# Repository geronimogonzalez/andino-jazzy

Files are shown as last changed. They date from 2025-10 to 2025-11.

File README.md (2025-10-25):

# ANDINO
[**BUILING BRANCH**]

Andino is a fully open-source diff drive robot designed for educational purposes and low-cost applications.
It is fully integrated with ROS 2 and it is a great base platform to improve skills over the robotics field.
With its open-source design, anyone can modify and customize the robot to suit their specific needs.

<p align="center">
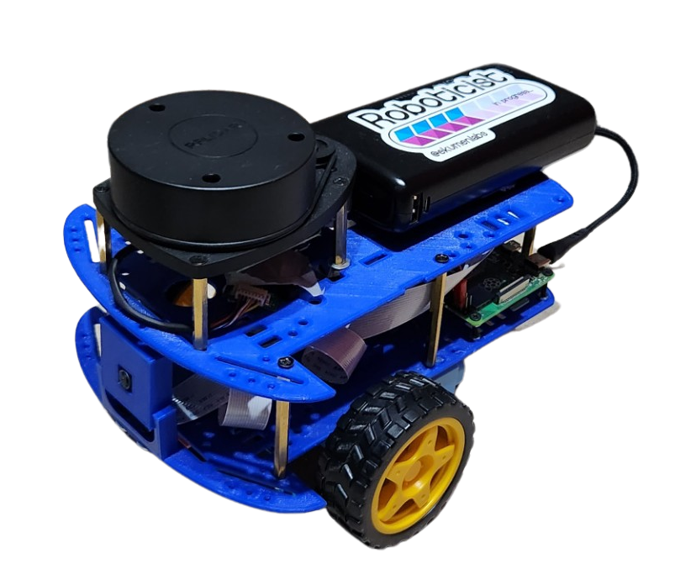
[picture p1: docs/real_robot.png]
  
</p>

_Note: For videos go to [Media](#selfie-media) section._

## :books: Package Summary

- :rocket: [`andino_bringup`](./andino_bringup): Contains mainly launch files in order to launch all related driver and nodes to be used in the real robot.
- :robot: [`andino_hardware`](./andino_hardware): Contains information about the Andino assembly and hardware parts.
- :ledger: [`andino_description`](./andino_description): Contains the URDF description of the robot.
- :hammer_and_pick: [`andino_firmware`](./andino_firmware): Contains the code be run in the microcontroller for interfacing low level hardware with the SBC.
- :gear: [`andino_base`](./andino_base): [ROS Control hardware interface](https://control.ros.org/master/doc/ros2_control/hardware_interface/doc/writing_new_hardware_interface.html) is implemented.
- :control_knobs: [`andino_control`](./andino_control/): It launches the [`controller_manager`](https://control.ros.org/humble/doc/ros2_control/controller_manager/doc/userdoc.html) along with the [ros2 controllers](https://control.ros.org/master/doc/ros2_controllers/doc/controllers_index.html): [diff_drive_controller](https://control.ros.org/master/doc/ros2_controllers/diff_drive_controller/doc/userdoc.html) and the [joint_state_broadcaster](https://control.ros.org/master/doc/ros2_controllers/joint_state_broadcaster/doc/userdoc.html).
- :world_map: [`andino_slam`](./andino_slam/): Provides support for SLAM with your `andino` robot.
- :compass: [`andino_navigation`](./andino_navigation/): Navigation stack based on `nav2`.

## :paperclips: Related projects

Other projects built upon Andino! :rocket:

- :computer: [`andino_gz`](https://github.com/Ekumen-OS/andino_gz): [Gazebo](https://gazebosim.org/home)(non-classic) simulation of the `andino` robot.
- :lady_beetle: [`andino_webots`](https://github.com/Ekumen-OS/andino_webots): [Webots](https://github.com/cyberbotics/webots) simulation of the Andino robot fully integrated with ROS 2.
- :joystick: [`andino_o3de`](https://github.com/Ekumen-OS/andino_o3de): [O3DE](https://o3de.org/) simulation of the Andino robot.
- :green_circle: [`andino_isaac`](https://github.com/Ekumen-OS/andino_isaac): [Isaac Sim](https://docs.omniverse.nvidia.com/isaacsim/latest/index.html) simulation of the Andino robot.
- :robot: [`andino_rmf`](https://github.com/Ekumen-OS/andino_rmf): [OpenRMF](https://www.open-rmf.org/) integration of Andino simulation.
- :test_tube: [`andino_integration_tests`](https://github.com/Ekumen-OS/andino_integration_tests): Extension to the Andino robot showing how to build integration tests.

## :busts_in_silhouette: Community

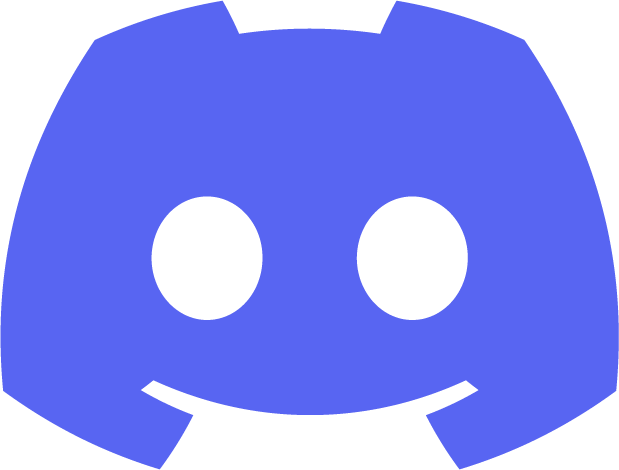
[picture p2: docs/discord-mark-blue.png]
[](https://discord.gg/tHhH32CTHu) Join our Discord and contribute to the community!

## :pick: Robot Assembly

Visit [`andino_hardware`](./andino_hardware/) for assembly instructions.

## :mechanical_arm: Installation

### Platforms

- ROS 2: Jazzy Jalisco
- OS:
  - Ubuntu 24.04 Noble Numbat
  - Ubuntu Server 24.04.1 (WIP) (On real robot (e.g: Raspberry Pi 4B))

### Build from Source

#### Dependencies

1. Install [ROS 2](https://docs.ros.org/en/jazzy/Installation/Ubuntu-Install-Debs.html)
2. Install [colcon](https://colcon.readthedocs.io/en/released/user/installation.html)

#### colcon workspace

Packages here provided are colcon packages. As such a colcon workspace is expected:

1. Create colcon workspace

```
mkdir -p ~/ws/src
```

2. Clone this repository in the `src` folder

```
cd ~/ws/src
```

```
git clone https://github.com/Ekumen-OS/andino.git
```

3. Install dependencies via `rosdep`

```
cd ~/ws
```

```
rosdep install --from-paths src --ignore-src -i -y
```

4. Build the packages

```
colcon build
```

5. Finally, source the built packages
   If using `bash`:

```
source install/setup.bash
```

`Note`: Whether your are installing the packages in your dev machine or in your robot the procedure is the same.

### Install the binaries

The packages have been also released via ROS package manager system for the 'humble' distro. You can check them [here](https://repo.ros2.org/status_page/ros_humble_default.html?q=andino).

These packages can be installed using `apt` (e.g: `sudo apt install ros-humble-andino-description`) or using `rosdep`.

## :rocket: Usage

### Robot bringup

`andino_bringup` contains launch files that concentrates the process that brings up the robot.

After installing and sourcing the andino's packages simply run.

```
ros2 launch andino_bringup andino_robot.launch.py
```

This launch files initializes the differential drive controller and brings ups the system to interface with ROS.
By default sensors like the camera and the lidar are initialized. This can be disabled via arguments and manage each initialization separately. See `ros2 launch andino_bringup andino_robot.launch.py -s ` for checking out the arguments.

- include_rplidar: `true` as default.
- include_camera: `true` as default.

After the robot is launched, use `ROS 2 CLI` for inspecting environment.
For example, by doing `ros2 topic list` the available topics can be displayed:

    /camera_info
    /cmd_vel
    /image_raw
    /odom
    /robot_description
    /scan
    /tf
    /tf_static

   _Note: Showing just some of them_

### Teleoperation

Launch files for using the keyboard or a joystick for teleoperating the robot are provided.

#### Keyboard

```
ros2 launch andino_bringup teleop_keyboard.launch.py
```
This is similarly to just executing `ros2 run teleop_twist_keyboard teleop_twist_keyboard`.

#### Joystick

Using a joystick for teleoperating is notably better.
You need the joystick configured as explained [here](andino_hardware/README.md#Using-joystick-for-teleoperation).
```
ros2 launch andino_bringup teleop_joystick.launch.py
```

### RViz

Use:

```
ros2 launch andino_bringup rviz.launch.py
```

For starting `rviz2` visualization with a provided configuration.

## :compass: Navigation

The [`andino_navigation`](./andino_navigation/README.md) package provides a navigation stack based on the great [Nav2](https://github.com/ros-planning/navigation2) package.

https://github.com/Ekumen-OS/andino/assets/53065142/29951e74-e604-4a6e-80fc-421c0c6d8fee

Follow the [`andino_navigation`'s README](./andino_navigation/README.md) instructions for bringing up the Navigation stack in the real robot or in the simulation.

## :selfie: Media

### RVIZ Visualization

https://github.com/Ekumen-OS/andino/assets/53065142/c9878894-1785-4b81-b1ce-80e07a27effd

### Slam

Using the robot for mapping.

https://github.com/Ekumen-OS/andino/assets/53065142/283f4afd-0f9a-4d37-b71f-c9d7b2f3e453

https://github.com/Ekumen-OS/andino/assets/53065142/d73f6053-b422-4334-8f62-029a38799e66

See [`andino_slam`](./andino_slam/) for more information.

## :robot: Share your Andino!

Have you built your `Andino` already? Please go to [`Show & Tell`](https://github.com/Ekumen-OS/andino/discussions/categories/show-and-tell) Discussion and share with us your own version of it.

## :star2: Inspirational sources

This section is dedicated to recognizing and expressing gratitude to the open-source repositories that have served as a source of inspiration for this project. We highly recommend exploring these repositories for further inspiration and learning.

 * [articubot_one](https://github.com/joshnewans/articubot_one)
 * [diffbot](https://github.com/ros-mobile-robots/diffbot)
 * [noah_hardware](https://github.com/GonzaCerv/noah-hardware)
 * [linorobot](https://github.com/linorobot/linorobot2)

## :raised_hands: Contributing

Issues or PRs are always welcome! Please refer to [CONTRIBUTING](CONTRIBUTING.md) doc.

## Code development

Note that a [`Docker`](./docker) folder is provided for easy setting up the workspace.

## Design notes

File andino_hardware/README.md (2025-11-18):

# andino_hardware

This package aims to provide the necessary information to the correct assembly of the robot.

## Bill of Materials

| Number | Module | Part | Links | Comments |
|:--:|:--:|:---:|:---:|:---:|
| 1 | SBC | Raspberry Pi 4 B (4 Gb) | [PiShop](https://www.pishop.us/product/raspberry-pi-4-model-b-2gb/), [TiendaTec](https://www.tiendatec.es/raspberry-pi/gama-raspberry-pi/1100-raspberry-pi-4-modelo-b-4gb-5056561800349.html) | If you want better performance you could buy the 8GB model |
| 2 | Chassis |  2 x Print 3d Chassis + Rubber Tyre Wheels | [Chassis](./printing_model/chassis/), [Wheels Sparkfun](https://www.sparkfun.com/products/13259) | - |
| 3 | Motors | 2 x Motor with Encoder | [Sparkfun](https://www.sparkfun.com/products/16413) | - |
| 4 | Microcontroller | Arduino Nano | [Amazon](https://www.amazon.es/RUIZHI-Interfaz-Controlador-Mejorada-Compatible/dp/B0CNGKG4MZ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) | You can also use an Arduino Uno, but mind size. It should include a microUSB - USB cable. If not, you will need to purchase it.  |
| 5 | Motor Driver | L298N Dual H Bridge | [Amazon](https://www.amazon.com/Bridge-Stepper-Driver-Module-Controller/dp/B09T6K9RFZ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) | - |
| 6 | Laser Scanner | RPLidar A1M8 | [RobotShop](https://www.robotshop.com/products/rplidar-a1m8-360-degree-laser-scanner-development-kit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), [Amazon](https://www.amazon.es/dp/B07VLFGT27?ref_=cm_sw_r_cso_wa_apan_dp_RJ3AZC2XCEVDK0X2DCGA&starsLeft=1&th=1) | If no microUSB-USB cable is included, you will need to purchase one |
| 7 | Camera | Raspi Camera Module V2, 8 MP | [Robotshop](https://www.robotshop.com/products/raspberry-pi-camera-module-v2), [Amazon](https://www.amazon.com/Raspberry-Pi-Camera-Module-Megapixel/dp/B01ER2SKFS?th=1), [Longer cable](https://www.amazon.es/AZDelivery-Repuesto-Raspberry-30cm-Flexkabel/dp/B01NAXKTDP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)  | A link for a longer cable (30 cm) is included, just in case the one included with the camera is too short. |
| 8 | Electrical Power Supply | Powerbank 5V | [Amazon](https://www.amazon.es/Heganus-Powerbank-10000mAh-port%C3%A1til-pr%C3%A1ctico/dp/B082PPPWXY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) | Any powerbank is suitable: Mind size / weight / output current(>=2A) |
| 9 | Power Step up | DC - DC boost converter | [Amazon Europe](https://www.amazon.es/Convertidor-convertidor-Controlador-almacenamiento-Transformadores/dp/B08D5XF571) | If motors support higher voltage than 5V a step-up(e.g: to 9V) can be added between powerbank (5V) and motor driver. Screw clockwise to reduce the output voltage. |
| 10 | Fixing & Mount | M3 bolts/fasteners - M3 Spacers - M2.5/2.0 bolts/fasteners for SBC | [Mercado Libre](https://articulo.mercadolibre.com.ar/MLA-823234605-kit-tornillos-electronica-500-unid-fresada-philips-m3-oferta-_JM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), [Amazon](https://www.amazon.com/Taiss-620PCS-Metric-Assortment-Washers/dp/B0CWXRG6VL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), [Spacers](https://www.amazon.es/YOKIVE-Separadores-Tornillos-Hexagonal-Consistente/dp/B0BWXL75R6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) | You will probably need to replace the default spacers for the LiDAR with M3 spacers |
| 11 | Other 3D printed parts | Camera Mount | [3D models](./printing_model/raspi_cam_mount/) | These parts are for fixing the Raspi Cam at the front of the robot |
| 12 | Caster wheel | Caster wheel | [Amazon](https://www.amazon.es/Unidades-Peque%C3%B1as-Dispositivo-Transferencia-Transporte/dp/B098XHYW7F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) | - |
| 13 | SD Card | 64 GB SD Card | [Apokin](https://www.apokin.es/tarjeta-microsd-philips-64gb-class10.html), [Amazon](https://www.amazon.es/Kingston-Tarjeta-SDCS2-64GB-Adaptador/dp/B07YGZQ4H8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) | The SD Card is used to host the OS for the Raspberry Pi |
| 14 | (Optional) Plastic seals | - | - | You will need at least 2 longer ones to fix the powerbank to the upper chassis, and the shorter ones for all the wires. If you don't want to use them, you can use other method to fix the powerbank and wires |

When you gather all the parts, you should have the following (NOTE: the printed encoder wheels are no longer necessary, since the motors are equipped with an embedded encoder):

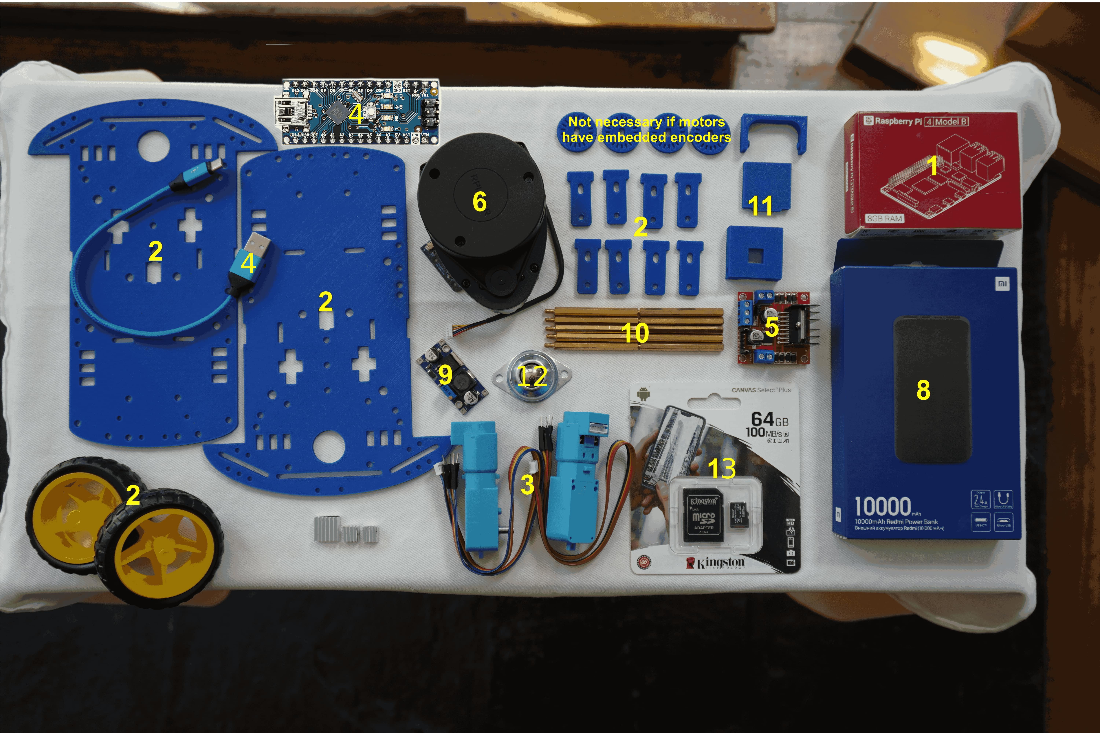
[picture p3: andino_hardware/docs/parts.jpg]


### Tooling

| Number | Tool | Links | Comments |
|:--:|:---:|:---:|:---:|
| 1 | Set of screwdrivers | [Amazon](https://www.amazon.es/Ainiv-Destornilladores-Precisi%C3%B3n-Destornillador-magnetizador/dp/B09CD1F44B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) | You need flat and star screwdrivers |
| 2 | Silicon Pistol | [Amazon](https://www.amazon.es/Tilswall-Pegamento-Manualidades-Bricolaje-Reparaciones/dp/B07TD1RD4R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) | This pistol should include 75 silicon bars so you won't need to purchase them separately |

## Assembly Process

  1. Screw the Motor Driver and the idler wheel to the lower chassis.

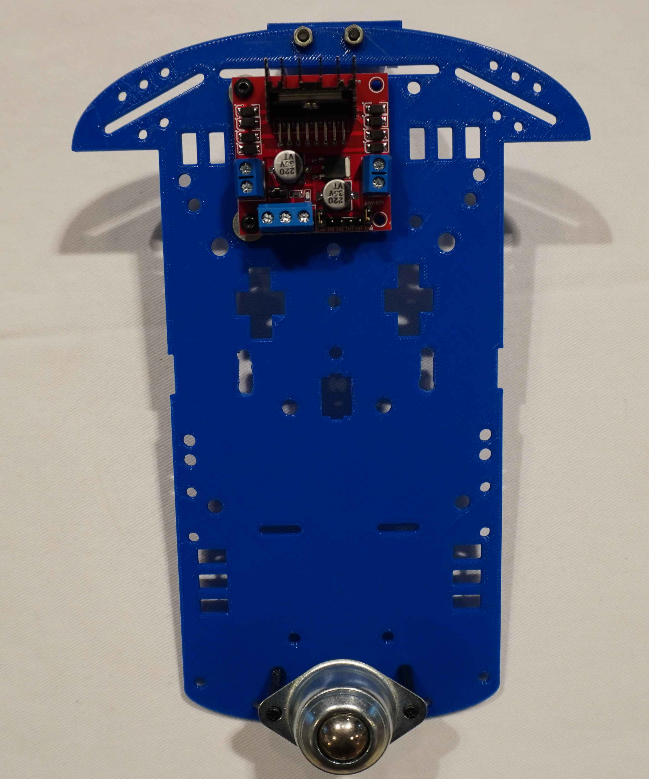
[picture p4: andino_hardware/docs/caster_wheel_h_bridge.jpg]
  

  Here you have a front image of how the caster wheel are mounted to the chassis:

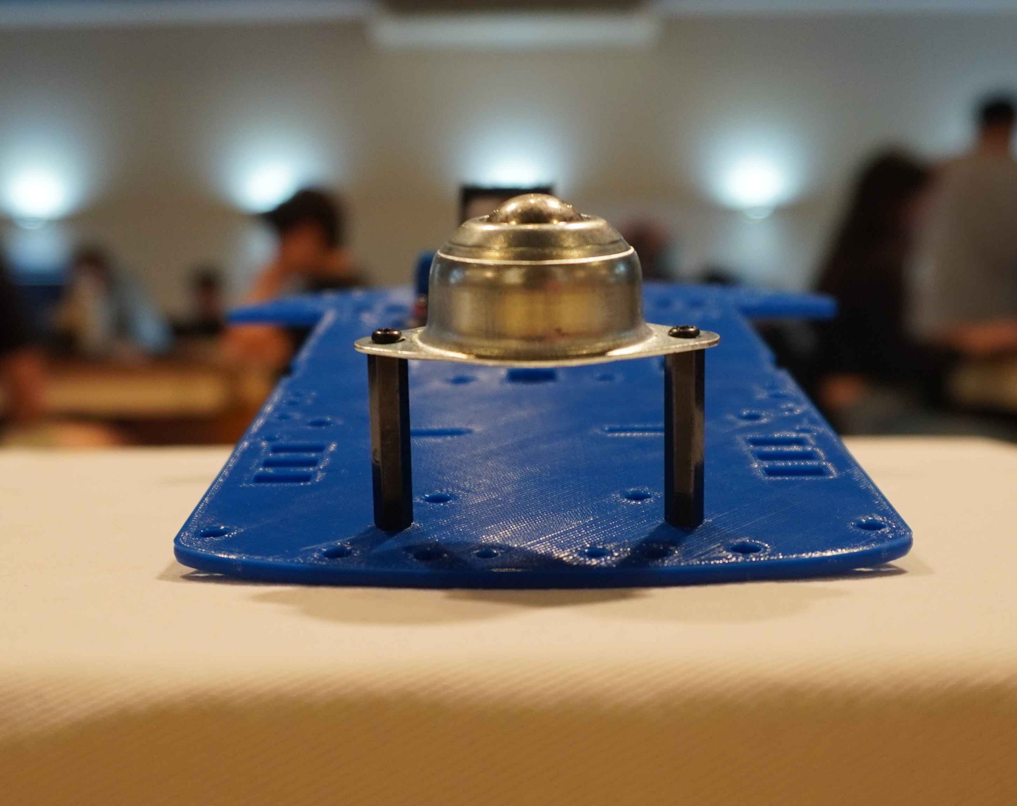
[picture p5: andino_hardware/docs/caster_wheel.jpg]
  

  2. Screw the 3D printed parts for the Raspi Camera Module:

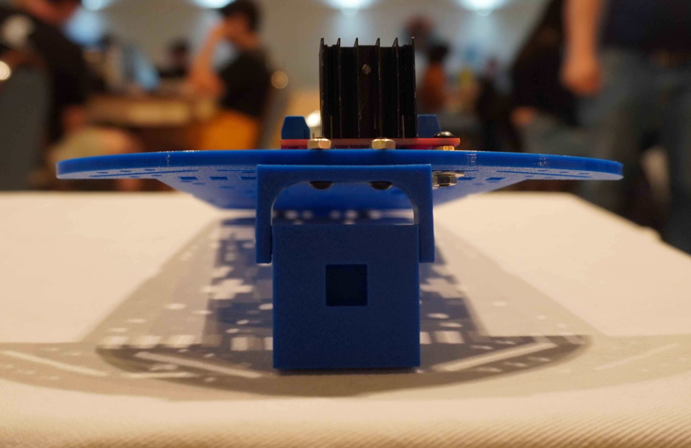
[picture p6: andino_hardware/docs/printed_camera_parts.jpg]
  

  3. Add the Arduino Nano to the back of the lower part of the chassis. It should look like this:

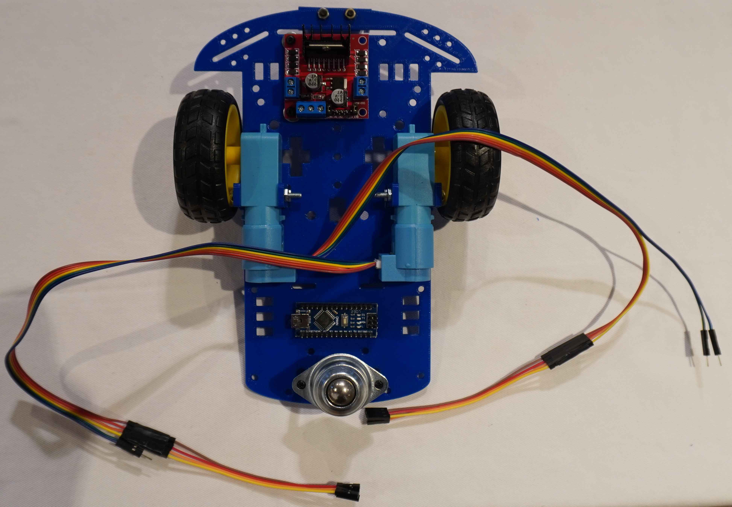
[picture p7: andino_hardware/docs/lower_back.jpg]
  

  4. Screw the Raspberry Pi and the DC-DC converter to the front of the lower part of the chassis:

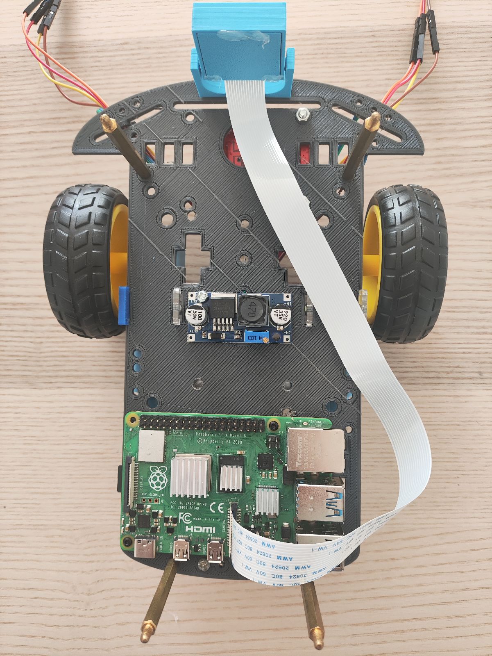
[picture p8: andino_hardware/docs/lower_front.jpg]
  

  5. Fix the powerbank to the back of the upper part of the chassis:

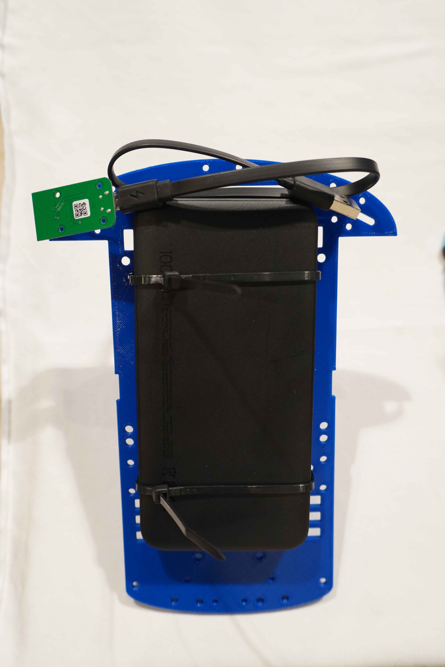
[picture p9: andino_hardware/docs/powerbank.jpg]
  

  6. Add the RPLidar to the front of the upper part of the chassis:

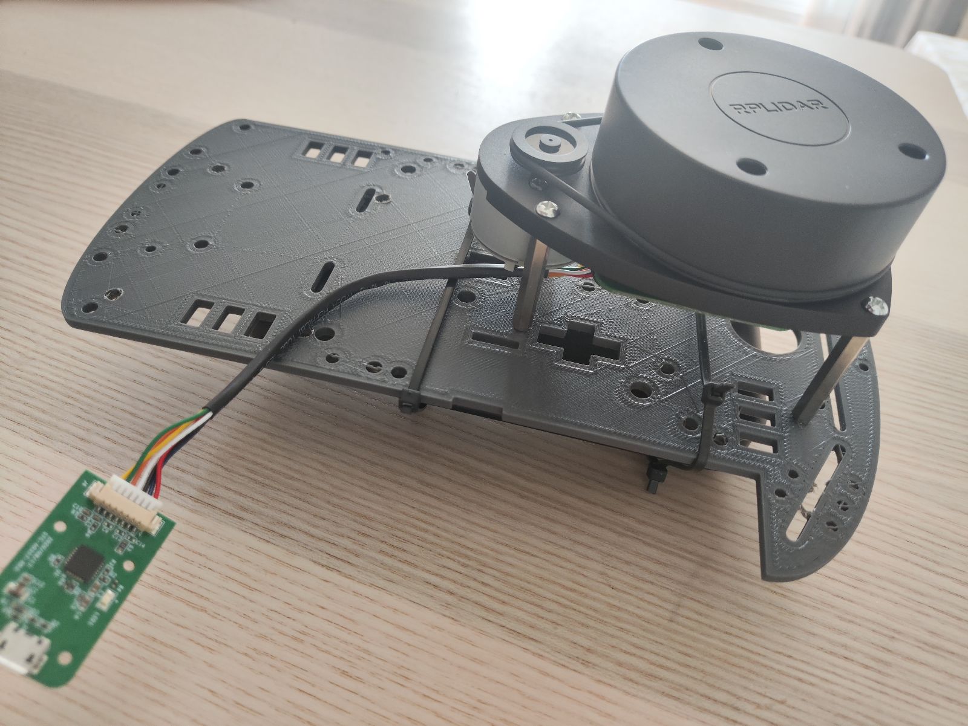
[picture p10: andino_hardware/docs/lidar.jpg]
  

  7. Add the IMU (WIP)

  <!-- TODO Add photo of the IMU physical implementation-->

  8. Perform all the wiring following the [Connections Diagram](#connection-diagram) of both the upper and lower chassis. Note that some of the connections may need to be done by soldering the cables.

  9.  Join both chassis together, and complete the remaining wiring to have your robot ready:

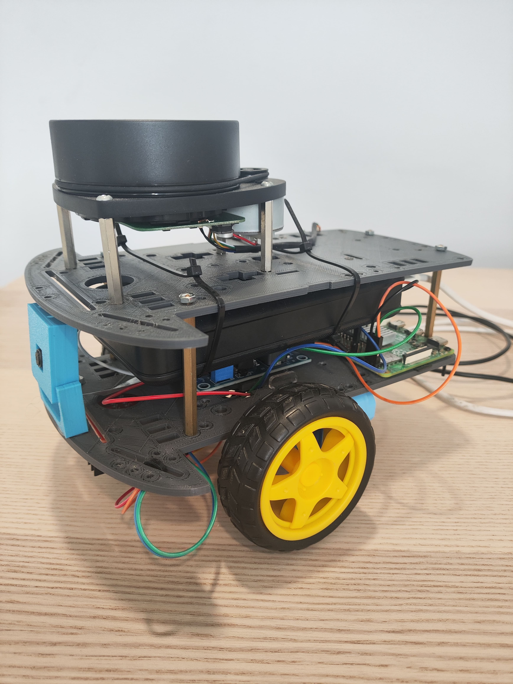
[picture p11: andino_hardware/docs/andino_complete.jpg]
  

## Connection Diagram

### Motor-Arduino

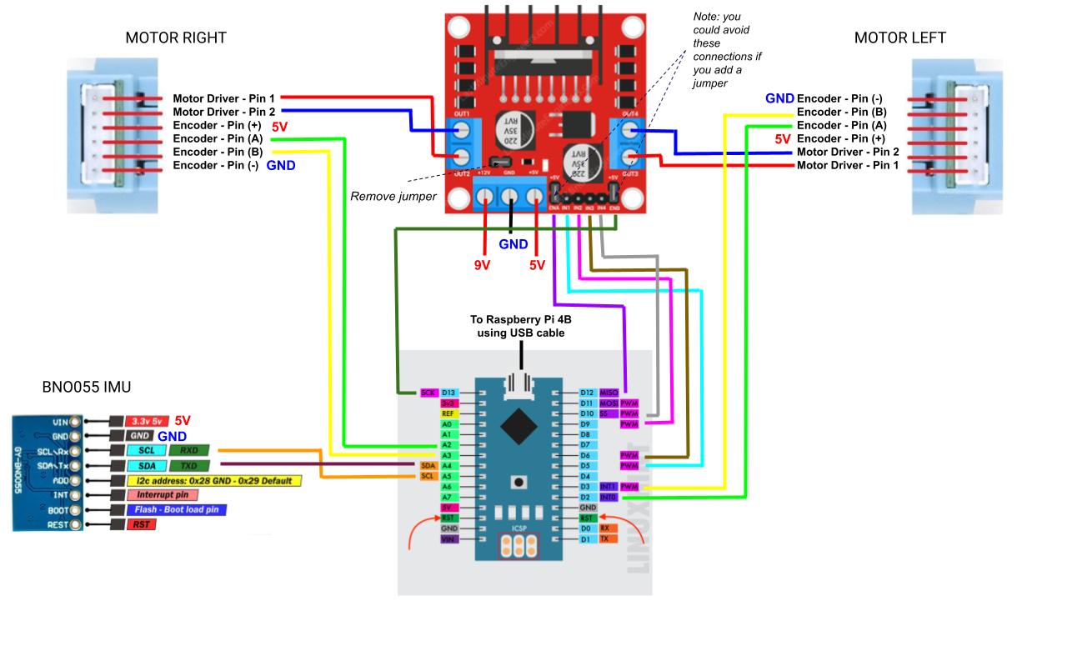
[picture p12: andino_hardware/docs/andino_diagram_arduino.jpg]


Some frequent errors:
 - If one of the motors rotates in the opposite direction (think about the orientation of the motors in the chassis) probably the output(+ and -) of the L298N's output should be toggled.
 - When moving forward the encoder values should increase while moving backwards they should decrease. If it is happening the other way around probably the A and B encoder signals should be toggled.

### Raspberry-Power

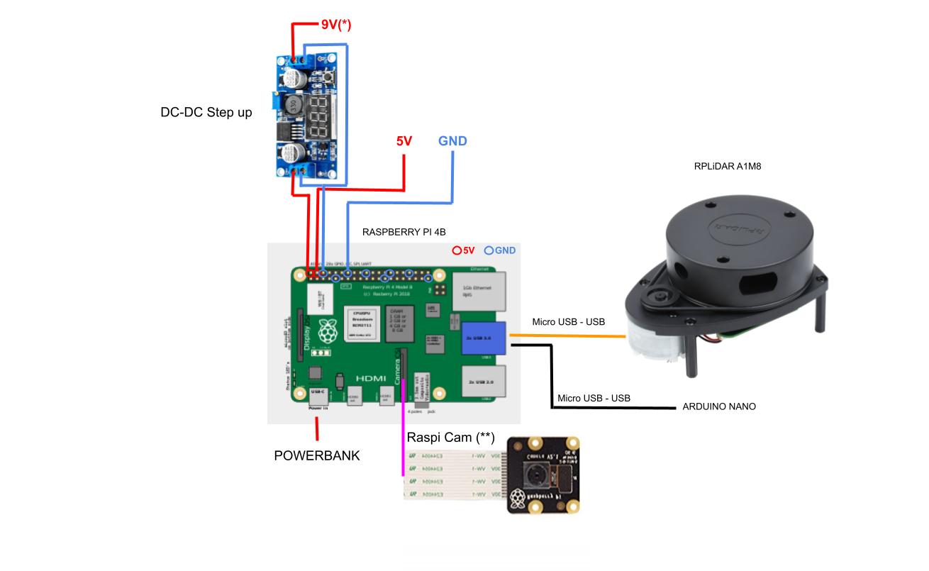
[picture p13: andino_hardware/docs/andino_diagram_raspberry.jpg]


*NOTE: depending on the power bank maximum output current, the motors may need to be powered with a voltage value lower than 9V. While a higher voltage value (up to 9V) leads to smoother operation (better motor speed control), it also increases their open-loop speed, which is noticeable particularly during motion start and varies according to the power bank quality (output current capabilities). Therefore, adjusting the output voltage to lower values (around 7V) may be required so as to make the motors work as expected.

**NOTE: Ensure the ribbon cable is properly connected with the blue or silver side facing the USB ports.

## Microcontroller Configuration

For uploading the microcontroller firmware please refer to [`andino_firmware`](../andino_firmware/README.md) package.

## Single Board Computer (SBC)

The SBC used in this project is a Raspberry Pi 4b so the guidelines here will refer particularly to this family of on-board computers, however extending its use to other families is possible as well.

### Operative System [WIP]

Ubuntu Server 24.04.1 is the recommended operative system for this project if you want to use the `jazzy` distro, since Ubuntu Mate 24 is not yet released.

For installing this OS in the Raspberry:
1. Download the image from here: [download Ubuntu 24 for Raspberry](https://ubuntu.com/download/raspberry-pi)

2. Install OS to a microSD card using [Raspberry Pi Imager](https://www.raspberrypi.com/software/).
   - No extra configuration should be necessary.

3. Boot your raspberry using the microSD and a HDMI connection. Some initial configuration is necessary. Follow the wizard for a proper set up. It is recommended to use simple User and Password combinations for the user. For example:
    - user: pi
    - password: admin
      
**recordar que el primer arranque debe ser conectado a internet mediante cable ethernet**

4. Once is done, run `sudo apt update && sudo apt upgrade` in a terminal for updating the system. Then reboot.

Para configurar la conecxion wifi descargar el paquete network manager
```
sudo apt-get install network-manager
```
y utilizar el comando 
```
sudo nmtui
```
para la configuracion de la red wifi deseada.

Recomendacion: Siempre trabajar con la mayor velocidad posible, por lo que si es posible trabajar bajo wifi 5.0 o cableado al menos una de las computadoras (ROV o station).
### Installing dependencies

Some packages are necessary to be installed towards a correct set up of the robot's on-board computer.

#### ssh-server

In general, you will want to access to the Raspberry remotely via `ssh` connection while being connected in the same network.
So we need to install `ssh-server`;
```
sudo apt-get install openssh-server
```
Enable it if it is not enabled yet:
```
sudo systemctl enable ssh --now
```

After this you will be able to access this device from a remote computer by doing:
```
ssh <user>@<ip>
```
For example if the user is `pi` and the ip is `192.168.0.102`
```
ssh pi@192.168.0.102
```

#### Common utilities

Install some common utilities that will be required later on.

```
sudo apt update
```

```
sudo apt install git net-tools software-properties-common build-essential -y
```
<font color="red"> el comando de abajo no existe. No lo corro y veo</font>

```
sudo apt install python3-rosdep2 python3-catkin-pkg python3-catkin-pkg-modules python3-rospkg-modules python3-rospkg  -y
```

#### Install ROS

Follow suit the instructions for installing next dependencies from binaries:
 - [ROS 2 Jazzy](https://docs.ros.org/en/jazzy/Installation/Ubuntu-Install-Debs.html)

Nota: Instalar ROS Jazzy Desktop, ya que contiene instaladas herramientas necesarias.

To automatically source ROS installation, it is recommended to add `source /opt/ros/humble/setup.bash` line to the `~/.bashrc` file.

#### Arduino

Arduino drivers are necessary for the SBC (Raspberry) <--> Microcontroller(Arduino) serial communication.

```
sudo apt install arduino
```

Configure it properly:
1. Add user to `dialout` and `plugdev` groups:
   ```
   sudo usermod -a -G dialout $USER
   ```
   ```
   sudo usermod -a -G plugdev $USER
   ```
   Note you will need a reboot after this to be effective.

#### Raspberry Camera Module V2

After connecting the camera module to the Raspberry's camera port.
```
sudo apt install libraspberrypi-bin v4l-utils
```
```
sudo usermod -aG video $USER
```

Check camera status:
```
vcgencmd get_camera
```

If the output of the previous command is `supported=1 detected=1', everything is fine. If not, your camera won't work correctly, you need to perform some configuration first.

Modify the `config.txt` file for the boot:

```sh
 sudo nano /boot/firmware/config.txt
```

And add these lines:

```
# Autoload overlays for any recognized cameras or displays that are attached
# to the CSI/DSI ports. Please note this is for libcamera support, *not* for
# the legacy camera stack
start_x=1
gpu_mem=128
```

Save and close the file. Then we need to enable the camera support for the raspberry:

```sh
sudo raspi-config
```

Go to `Interface Options`, select `camera` and enable it.

Finally, you just need to reboot and the camera should be working fine.

#### RPLidar installation

The installation of the A1M8 RPLidar sensor is quite straight forward and a ros integration package will be installed later on via `rosdep`.

For now, after connecting it to the usb port:
 1. Verify USB connection: Green light in the usb conversor(A1M8 side board) should be turned on.
 2. Check the authority of RPLidar's serial-port:
    - `ls -l /dev |grep ttyUSB`
    - Add extra bits by doing `sudo chmod 666 /dev/ttyUSB<number_of_device>`

### USB Port name configuration

#### Fixed USB port names

As having multiple USB devices connected to the USB ports of the Raspberry Pi, the automatically assigned USB port numbers could unexpectedly change after a reboot.
To avoid assigning your device to a `tty_USBX` number that isn't the correct one we should assign fixed USB port name for each connected device.

The idea is to be able to generate a link between the real `ttyUSBX` port and an invented one. For this we will need to create rules, that every time the Raspberry Pi boots are executed, and therefore we
always point to the correct port name.

In order to create fixed names for the USB devices follow the instructions:

1. Check the devices you have connected:
    ```
    sudo dmesg | grep ttyUSB
    ```

    ```
    [  10.016170] usb 1-1.2: ch341-uart converter now attached to ttyUSB0
    [ 309.186487] usb 1-1.1: cp210x converter now attached to ttyUSB1
    ```
    In the setup where this was tested we have:
      -> Arduino Microcontroller -> _usb 1-1.2: ch341-uart converter now attached to ttyUSB0_
      -> A1M8 Lidar Scanner -> _usb 1-1.1: cp210x converter now attached to ttyUSB1_

    _Note: If you don't know how to identify each one you can simply connect them one by one and check this output._

2. Look for attributes for each device that we will use to anchor a particular device with a name.
  We will use the `idProduct` and `idVendor` of each device.
   - Arduino Microcontroller:
      ```
      udevadm info --name=/dev/ttyUSB0 --attribute-walk
      ```
      You should look for the `idProduct` and `idVendor` under the category that matches the usb number(1-1.X):
      In this case the `ttyUSB0` was referenced to the `usb 1-1.2`, so go to that section and find the ids:
      ```
        ATTRS{idProduct}=="7523"
        ATTRS{idVendor}=="1a86"
      ```
   - Lidar Scanner
      ```
      udevadm info --name=/dev/ttyUSB1 --attribute-walk
      ```
      In this case the `ttyUSB0` was referenced to the `usb 1-1.1`, so go to that section and find the ids:
      ```
        ATTRS{idProduct}=="ea60"
        ATTRS{idVendor}=="10c4"
      ```

3. Create the rules:

    Open the file:
    ```
    sudo nano /etc/udev/rules.d/10-usb-serial.rules
    ```

    Add the following:

    ```
    SUBSYSTEM=="tty", ATTRS{idProduct}=="7523", ATTRS{idVendor}=="1a86", SYMLINK+="ttyUSB_ARDUINO"
    SUBSYSTEM=="tty", ATTRS{idProduct}=="ea60", ATTRS{idVendor}=="10c4", SYMLINK+="ttyUSB_LIDAR"
    ```
    Note that in the `symlink` field a fixed name is indicated.

4. Re-trigger the device manager:
    ```
    sudo udevadm trigger
    ```

5. Verify
    ```
    ls -l /dev/ttyUSB*
    ```
    ```
    crw-rw---- 1 root dialout 188, 0 Sep  2 15:09 /dev/ttyUSB0
    crw-rw---- 1 root dialout 188, 1 Sep  2 15:09 /dev/ttyUSB1
    lrwxrwxrwx 1 root root         7 Sep  2 15:09 /dev/ttyUSB_ARDUINO -> ttyUSB0
    lrwxrwxrwx 1 root root         7 Sep  2 15:09 /dev/ttyUSB_LIDAR -> ttyUSB1
    ```

Done! You can always use your devices by the fixed names without using the port number.
Here, `ttyUSB_ARDUINO` and `ttyUSB_LIDAR` are fixed names for the Arduino Microcontroller and the Lidar Scanner respectively.

For more information you can take a look at this external tutorial: [Here](https://www.freva.com/assign-fixed-usb-port-names-to-your-raspberry-pi/)

### Create robot workspace

Let's create our workspace and build from source this repository.

```
cd ~
```
```
mkdir robot_ws/src -p
```
Clone this repository in the `src` folder
```
cd robot_ws/src
```
```
git clone <repository_address>
```
Install dependencies via rosdep:
```
cd ~/robot_ws
```
When it is the first time you run `rosdep`:
```
rosdep update
```
Make sure to export the `ROS_DISTRO` environment variable:
```
export ROS_DISTRO=humble
```
And then proceed to install the workspace dependencies:
```
sudo apt install python3-rosdep
sudo rosdep init
rosdep install --from-paths src -i -y -r
```
Note that option `-r` has been added. For ARM based processors, there are missing packages, e.g. those related to simulation. We would not try to run the simulation in the compute platform of andino, however for convenience it is added here.

Let' source the ROS Humble installation:
```
source /opt/ros/humble/setup.bash
```
Let's build the packages:
```
colcon build
```
After building is completed:
```
source install/setup.bash
```

After this, you are good to go and use the robot!
Refer to [`usage`](../README.md#usage) section.

### Extra Recommendations & Tools

#### Network
Via terminal the wifi connection can be switched by doing:

List available wifi networks:
```
sudo nmcli dev wifi list
```
Connect to the desired one:
```
sudo nmcli --ask dev wifi connect <SSID>
```

#### Copy files remotely

Using `scp` is a useful tool when copying files remotely over `ssh`.

For copying a folder from host to remote unit:
```
scp -r <path/to/folder> <remote_user>@<remote_ip>:<remote_path_to_folder>
```

#### ROS Domain ID

The domain ID is used by DDS to compute the UDP ports that will be used for discovery and communication.

When using a "public" network using the domain id is a good technique to avoid extra noise with other ROS 2 system in the same network.

See [ROS_DOMAIN_ID](https://docs.ros.org/en/humble/Concepts/Intermediate/About-Domain-ID.html)

TLDR? Export an environment variable with the same ID in **all** ROS 2 clients in the network for a correct discovery.
```
export ROS_DOMAIN_ID=<a_number_between_0_and_101>
```

#### Using joystick for teleoperation

[`andino_bringup`](../andino_bringup/launch/teleop_joystick.launch.py) package provides a launch file for launching the corresponding `ROS 2` nodes for teleoperating the robot using a joystick.

It is worth mentioning that a set up might be needed depending on the gamepad you are using. Here some general guidelines:
 - In case you are using a _Xbox One Controller_ and you want use it wireless (via USB Wirless Dongle) installing [Xone](https://github.com/medusalix/xone) is recommended.
 - Verify that your joystick is actually working on Ubuntu:
    - Some tools that might be useful:
      - `sudo apt install joystick jstest-gtk evtest`
    - Run `evtest` to check if your pad is connected:
      ```
      $ evtest
        No device specified, trying to scan all of /dev/input/event*
        Not running as root, no devices may be available.
        Available devices:
          /dev/input/event22:	Microsoft X-Box One pad

      ```
    - Alternatively, you can use `jstest-gtk` to check the controller, you will find a pretty GUI to play with.

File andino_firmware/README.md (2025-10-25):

# andino_firmware

Firmware code to be run in the arduino microcontroller for proper control of the motors of the robot.

## Connection

Check `hw.h` file to check the expected pins for the connection for motors, encoders and IMU.

## Installation

### Arduino
In Arduino IDE, go to `tools->Manage Libraries ...` and install:
- "Adafruit BNO055"

Verify and Upload `andino_firmware.ino` to your arduino board.

### PlatformIO
1. Install dependencies `sudo apt-get install python3.10-venv`
2. Install platformio
```
curl -fsSL -o /tmp/get-platformio.py https://raw.githubusercontent.com/platformio/platformio-core-installer/master/get-platformio.py
python3 /tmp/get-platformio.py
```
3. Add platformio to your $PATH:
```
echo "PATH=\"\$PATH:\$HOME/.platformio/penv/bin\"" >> $HOME/.bashrc
source $HOME/.bashrc
```
4. Build and upload the firmware
   - If you're using an arduino uno `pio run --target upload -e uno`
   - If you're using an arduino nano `pio run --target upload -e nanoatmega328`

## Description

Via `serial` connection (57600 baud) it is possible to interact with the microcontroller. The interface is described in the [commands.h](src/commands.h) file. Here are the most used commands:

 - Get encoder values: `'e'`
 - Set open-loop speed for the motors[pwm] `'o <left> <right>'`
   - Example to move forward full speed: `'o 255 255'`
   - Range `[-255 -> 255]`
 - Set closed-loop speed for the motors[ticks/sec] `'m <left> <right>'`
   - Important!: See the `Test it!` section.
 - Set PID values: `'u <kp> <kd> <ki> <offset>'`

Note: Remember the carriage return character at the end of the message.

## Test it!

A serial port connection must be created at 57600 bauds. You can use the serial monitor from Arduino IDE for example.

* Open loop verification:
  - Send `o 255 255` to go full speed
  - Send `o 0 0` to stop it.

* Read the encoders
  - Send `e` to get the encoders values.

* Get the ticks per revolution of your motor.
  - First set the encoders to zero, (reeboting with `r`).
  - Then rotate your motors as many revs you want,(say 10 for example) and then divide the encoder ticks per the number of revs. -> Then you get the ticks per revolution. Save this value, it is calibration for the control loop.

* Closed loop verification
  - Send `m <tps> <tps>` where `tps` stands for `ticks per second`. For example if your motor-encoder system gets 700 ticks per revolution then sending `m 700 700` will rotate both motors at 1 rev per sec. (~3.14rad/sec)

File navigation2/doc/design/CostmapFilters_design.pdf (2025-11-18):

# Costmap Filters High-Level Design

v.1.1

## ROS2 Overall Structure

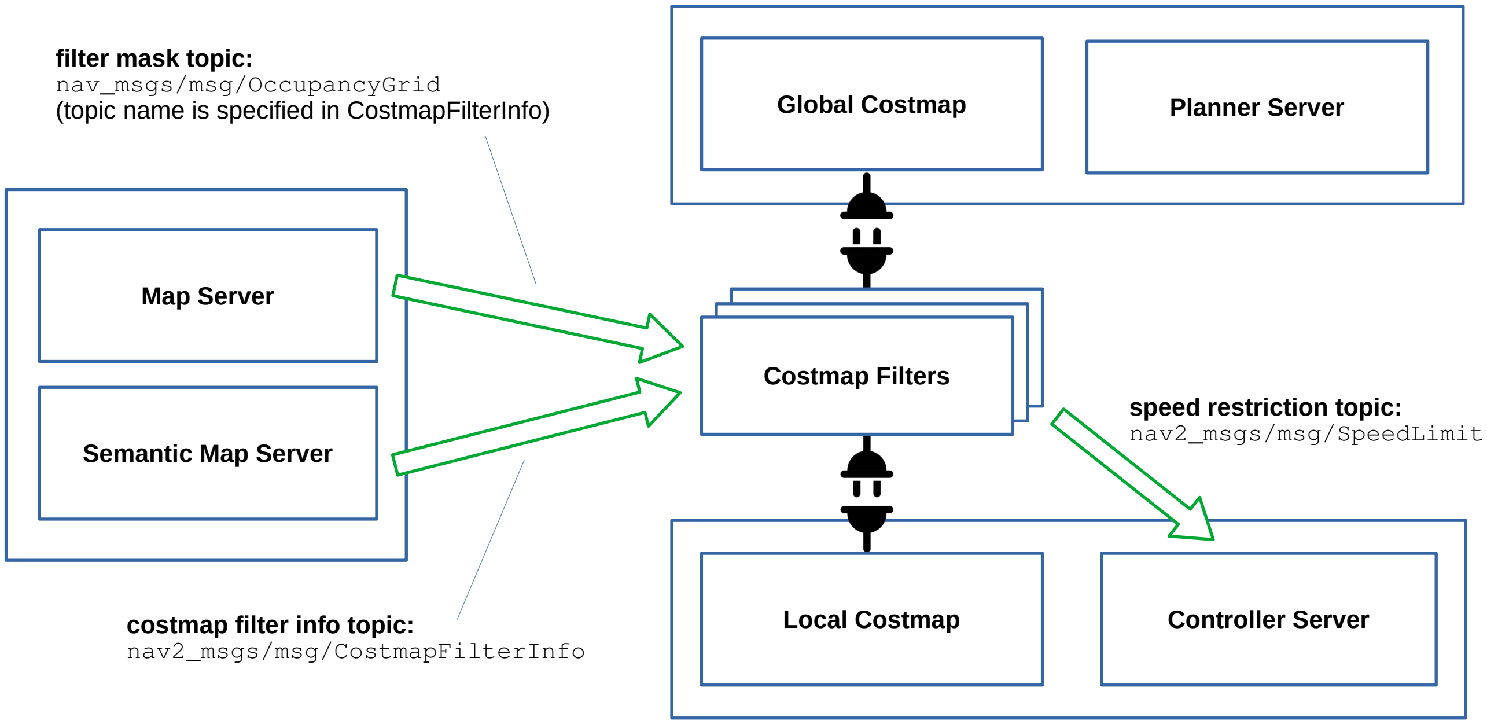
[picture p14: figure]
Controller Server; filter mask topic: nav_msgs/msg/OccupancyGrid; Local Costmap; Global Costmap; Planner Server; speed restriction topic: nav2_msgs/msg/SpeedLimit; Map Server; Semantic Map Server; costmap filter info topic: nav2_msgs/msg/CostmapFilterInfo

(topic name is specified in CostmapFilterInfo)

Costmap Filters Costmap Filters Costmap Filters

CostmapLayer

KeepoutFilter
loadFilter() - Creates a subscription to filter_info and filter_mask topics.

process() - Based on loaded map composes Costmap2D with
[FREE_SPACE..LETHAL_OBSTACLE] cost depending on data value in filter_mask.

SpeedFilter
loadFilter() - Creates a subscription to filter_info and filter_mask topics. Creates a publisher for speed_limit topic.

process() - Checks whether the robot is entered or leaved marked on map speed restriction area. If entered checks the speed limit and sets speed_limit topic value. If leaved restores back speed_limit topic value to no-limit.

LanesFilter
Covered by KeepoutFilter (#1522). (https://github.com/ros-planning/navigation2/issues/1522)

CostmapFilter
class CostmapFilter {
public:
virtual initializeFilter(
const std::string & filter_info_topic) = 0; virtual process(
Costmap2D & master_grid, int window_bounds, Pose2D & robot_pose) = 0;
virtual resetFilter() = 0;

protected:
pose last_robot_pose;
};

CostmapFilter::activate() {
// Creates subscriptions to info and mask topics initializeFilter(filter_info_topic);
}

CostmapFilter::deactivate() {
// Reset all subscriptions resetFilter(filter_info_topic); }

CostmapFilter::reset() {
// Reloads filter
resetFilter();
initializeFilter(filter_info_topic);
}

CostmapFilter::updateBounds(robot_pose, bounds) { ...
last_robot_pose = robot_pose;
}

CostmapFilter::updateCosts(
Costmap2D & master_grid, int window_bounds) { ...
// An algorithm for how to use that map's
// information. Fills the Costmap2D with
// calculated data and makes an action based
// on processed data.
process(master_grid, window_bounds, last_robot_pose); }

## Costmap Filters Structure

class
inheritance

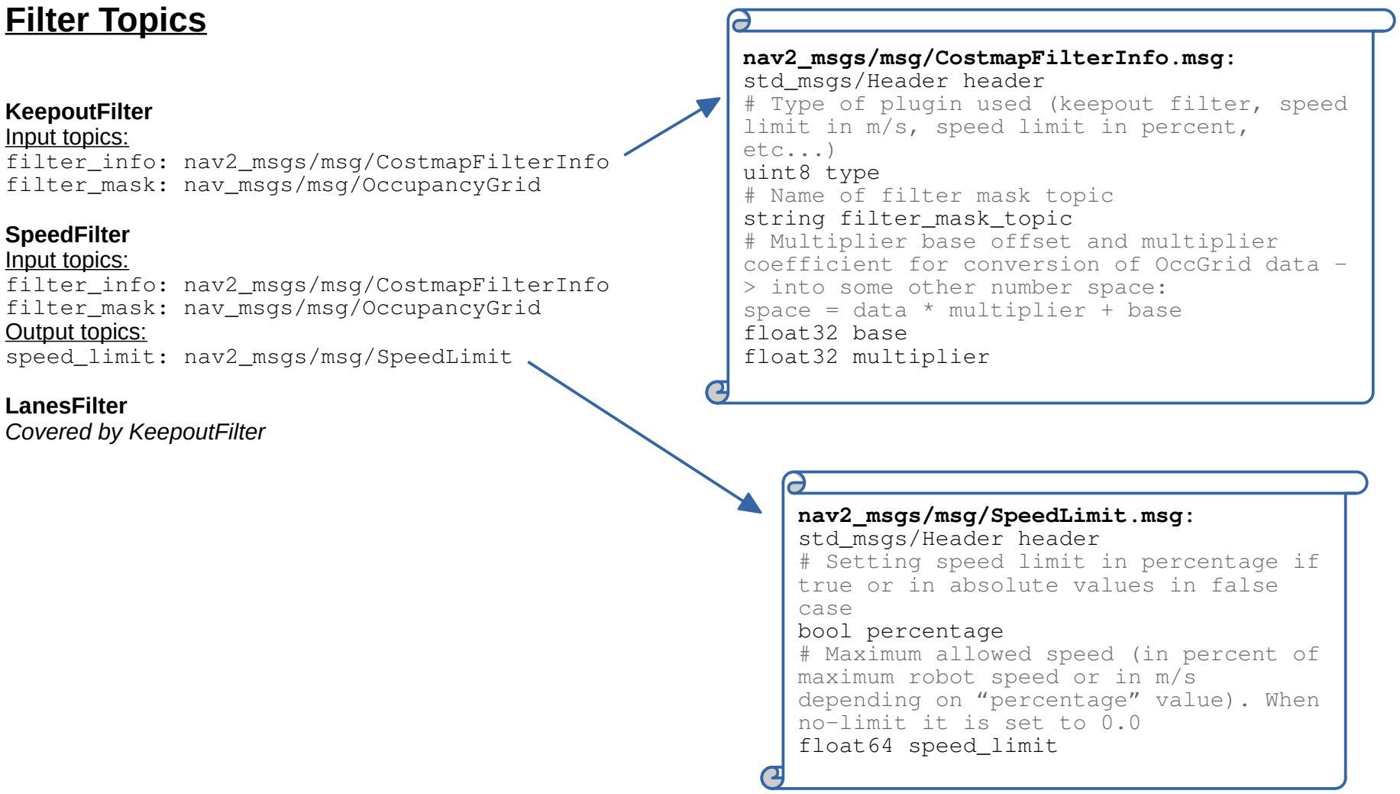
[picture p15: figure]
KeepoutFilter Input topics: filter_info: nav2_msgs/msg/CostmapFilterInfo filter_mask: nav_msgs/msg/OccupancyGrid; SpeedFilter Input topics: filter_info: nav2_msgs/msg/CostmapFilterInfo filter_mask: nav_msgs/msg/OccupancyGrid Output topics: speed_limit: nav2_msgs/msg/SpeedLimit; LanesFilter Covered by KeepoutFilter; Filter Topics; nav2_msgs/msg/CostmapFilterInfo.msg: std_msgs/Header header; limit in m/s, speed limit in percent, etc...) uint8 type # Name of filter mask topic string filter_mask_topic # Multiplier base offset and multiplier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

# Type of plugin used (keepout filter, speed

coefficient for conversion of OccGrid data -

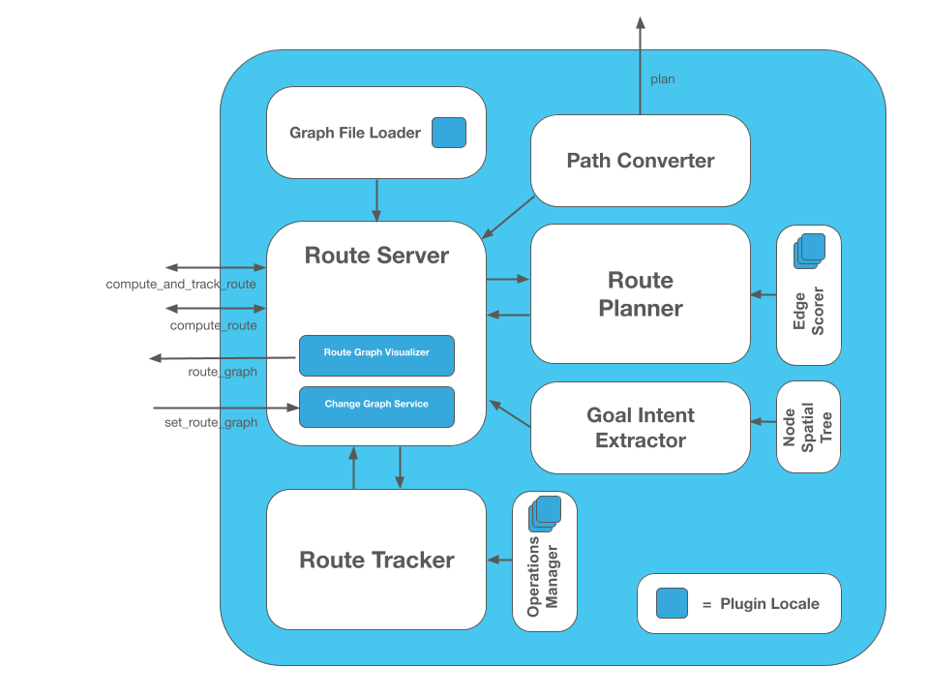
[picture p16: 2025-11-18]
navigation2/nav2_route/media/architecture.png

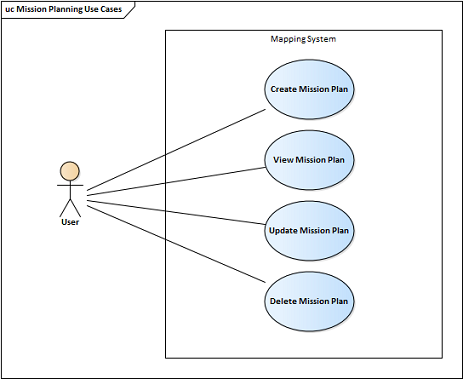
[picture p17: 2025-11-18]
navigation2/doc/requirements/images/Mission-Planning-Use-Cases.png

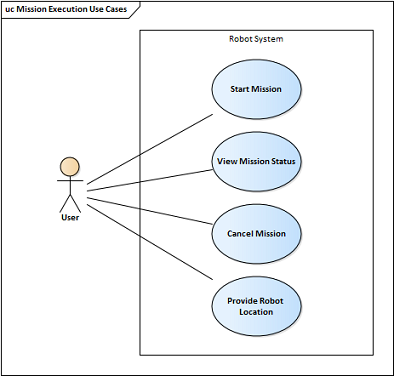
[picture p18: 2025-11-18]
navigation2/doc/requirements/images/Mission-Execution-Use-Cases.png

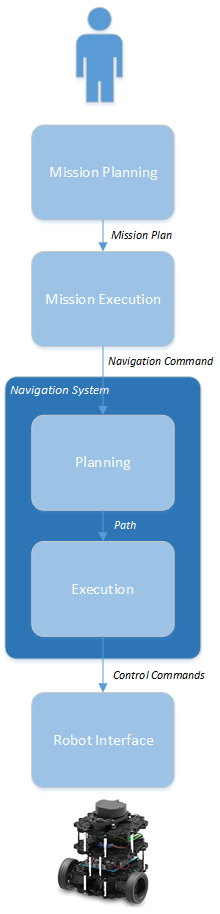
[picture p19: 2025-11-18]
navigation2/doc/requirements/images/Command-Pipeline.png

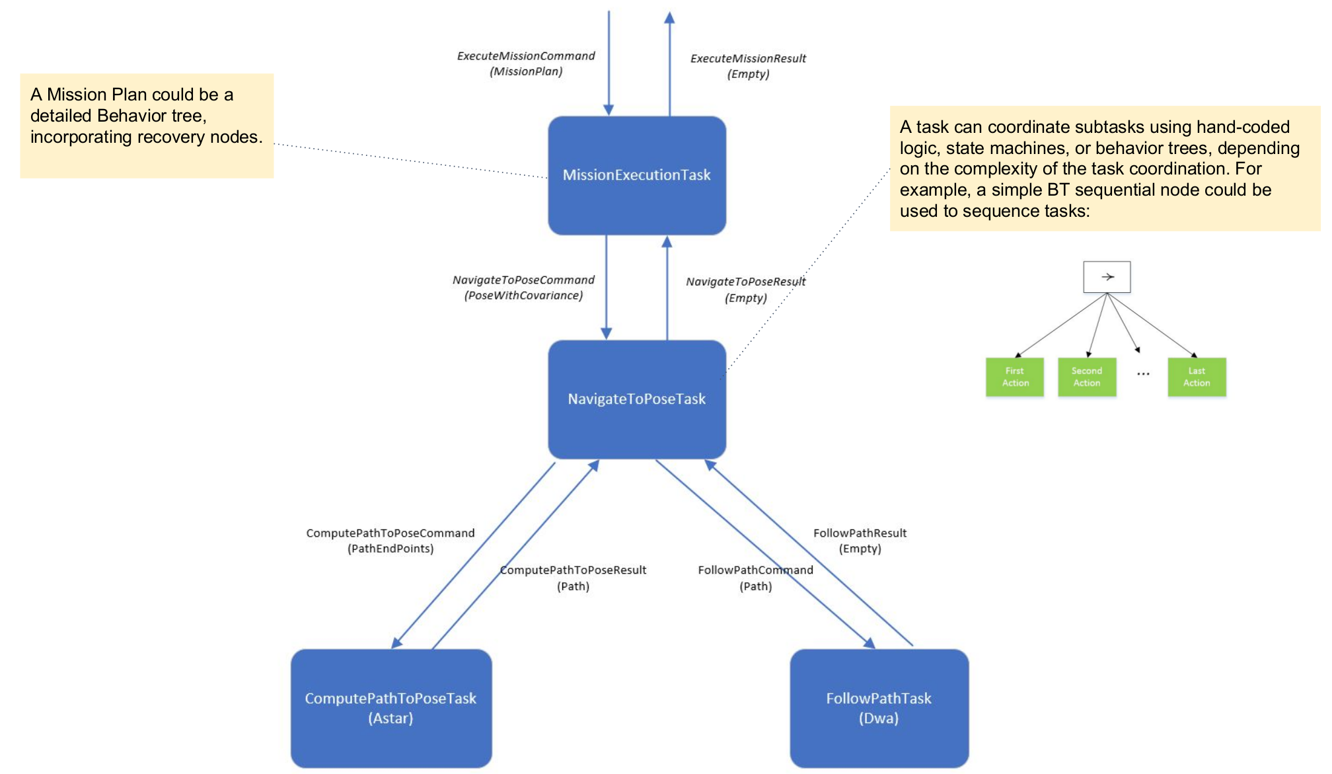
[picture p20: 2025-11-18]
navigation2/doc/design/NavigationSystemTasks.png

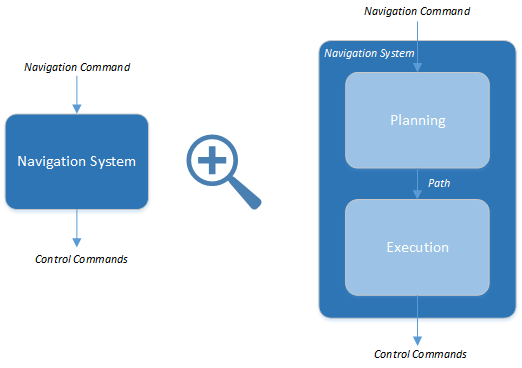
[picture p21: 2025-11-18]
navigation2/doc/requirements/images/Navigation-System.png

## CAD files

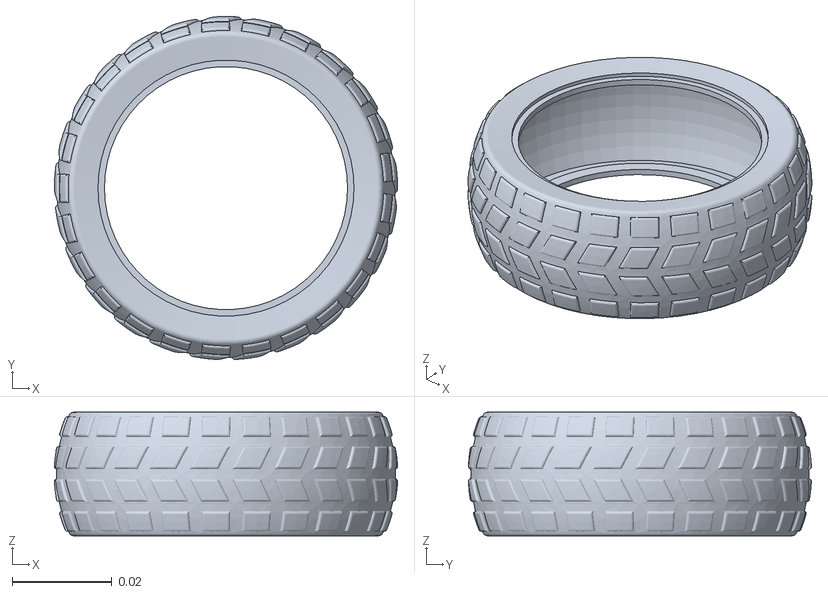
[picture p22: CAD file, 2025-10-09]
andino_description/meshes/andino/wheel_tire.stl
0.0689 x 0.0689 x 0.0248

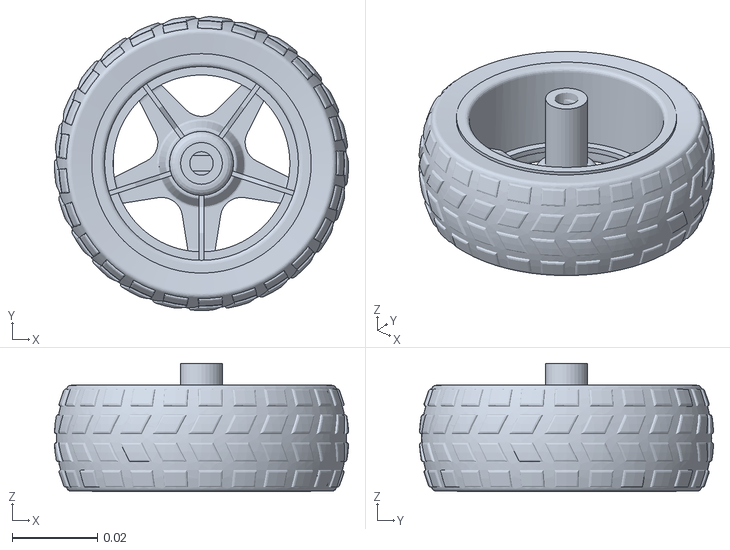
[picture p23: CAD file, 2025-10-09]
andino_description/meshes/components/wheel.stl
0.0689 x 0.0689 x 0.03

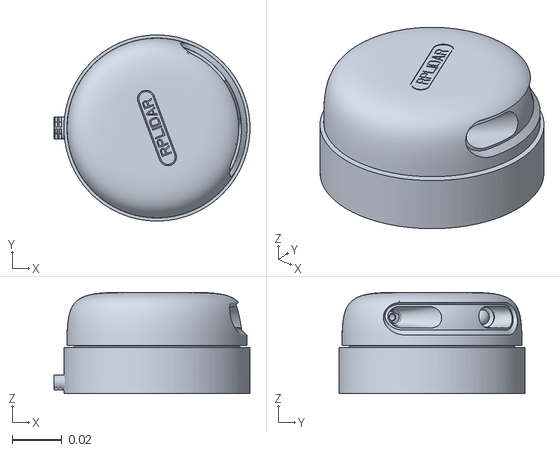
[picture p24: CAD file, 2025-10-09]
andino_description/meshes/sensors/rplidar-a2.stl
0.079 x 0.075 x 0.0408

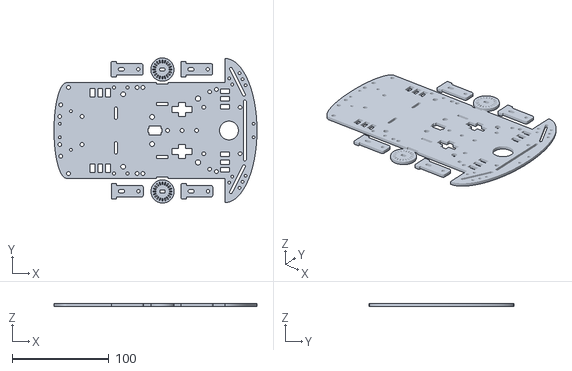
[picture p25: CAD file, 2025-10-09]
andino_hardware/printing_model/chassis/RobotChassis.STL
210.0 x 150.1 x 3.00

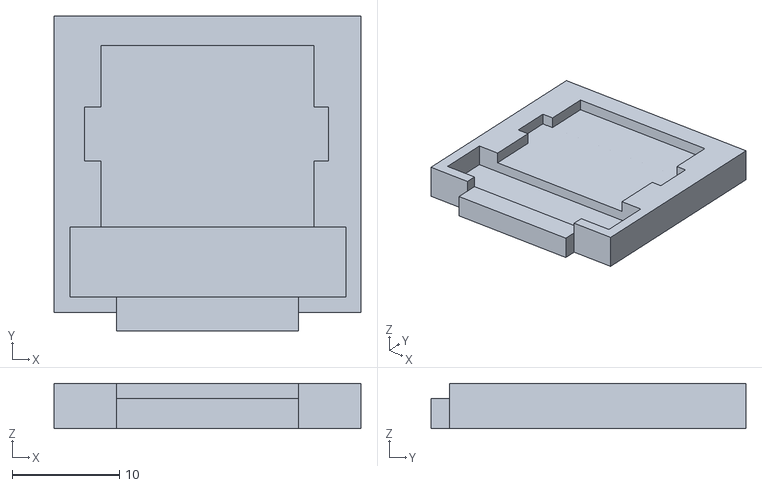
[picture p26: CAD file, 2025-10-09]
andino_hardware/printing_model/raspi_cam_mount/raspi_camera_mount_back.stl
28.6 x 29.3 x 4.20

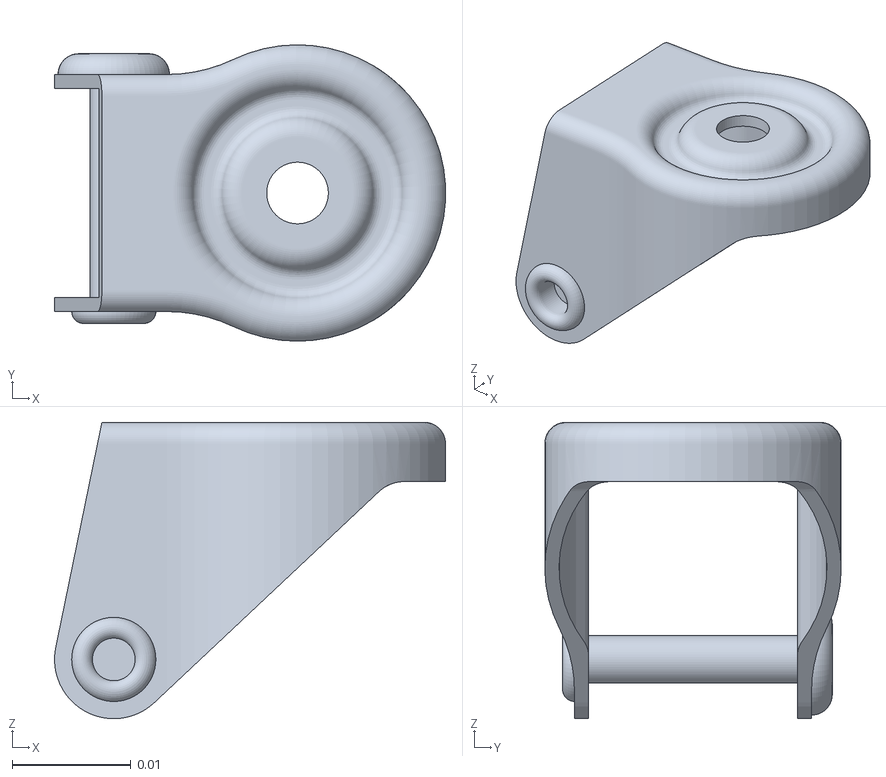
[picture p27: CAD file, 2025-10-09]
andino_description/meshes/andino/caster_wheel_support.stl
0.033 x 0.025 x 0.025

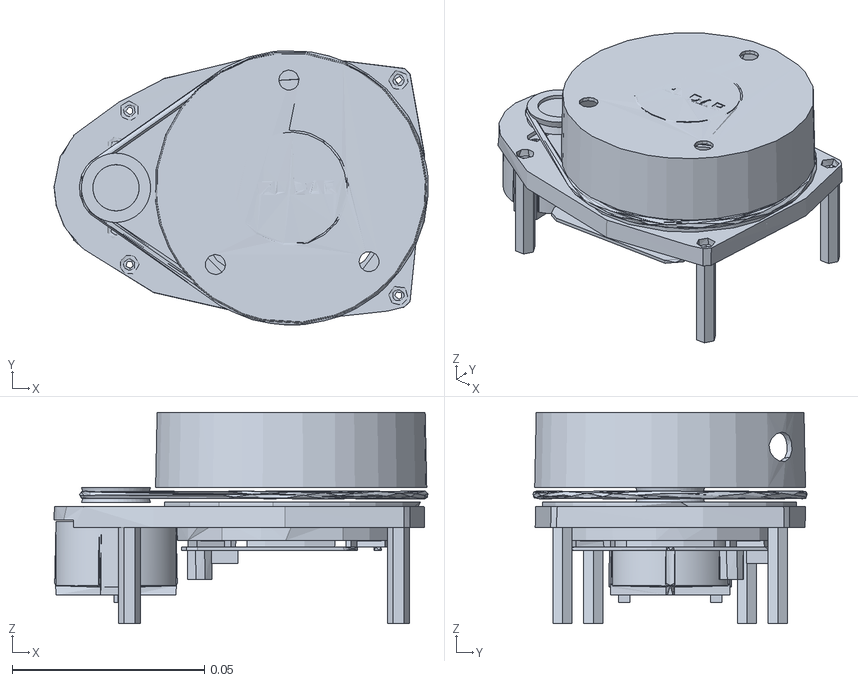
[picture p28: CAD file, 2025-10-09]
andino_description/meshes/sensors/rplidar-a1.stl
0.0973 x 0.0714 x 0.055

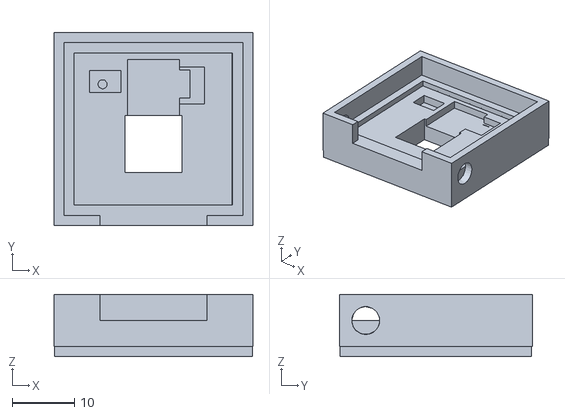
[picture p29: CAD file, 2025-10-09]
andino_hardware/printing_model/raspi_cam_mount/raspi_camera_mount_front.stl
32.0 x 31.0 x 10.0

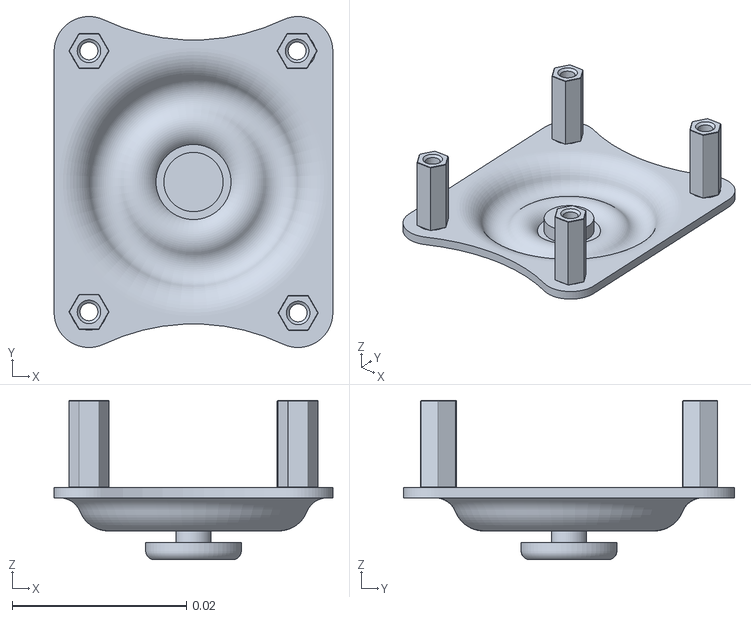
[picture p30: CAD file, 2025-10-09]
andino_description/meshes/andino/caster_base.stl
0.032 x 0.038 x 0.0183

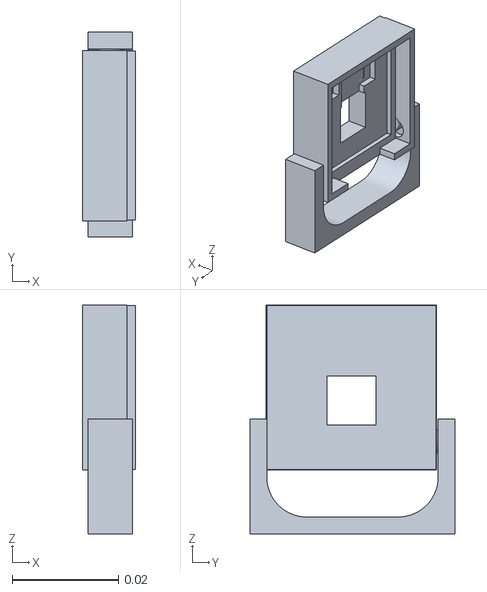
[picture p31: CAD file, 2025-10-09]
andino_description/meshes/sensors/camera_mount.stl
0.01 x 0.0386 x 0.043

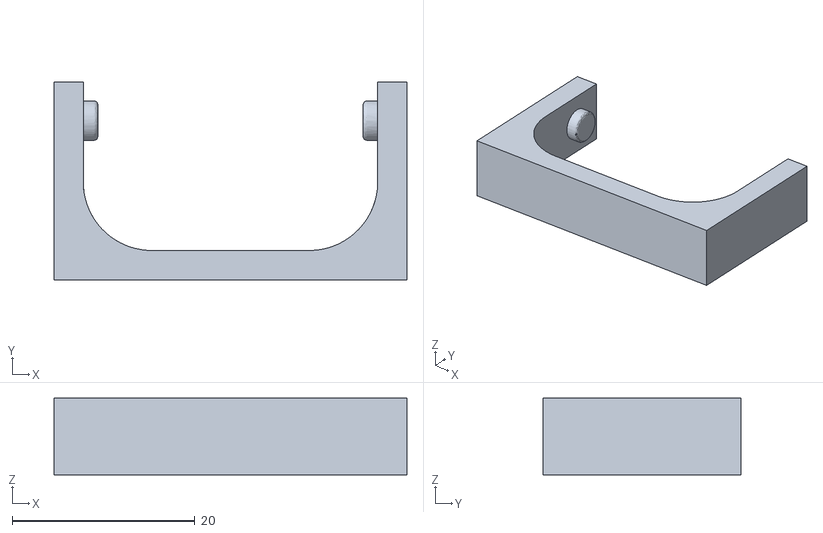
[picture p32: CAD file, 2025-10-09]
andino_hardware/printing_model/raspi_cam_mount/raspi_camera_mount_hinge.stl
38.6 x 21.6 x 8.40

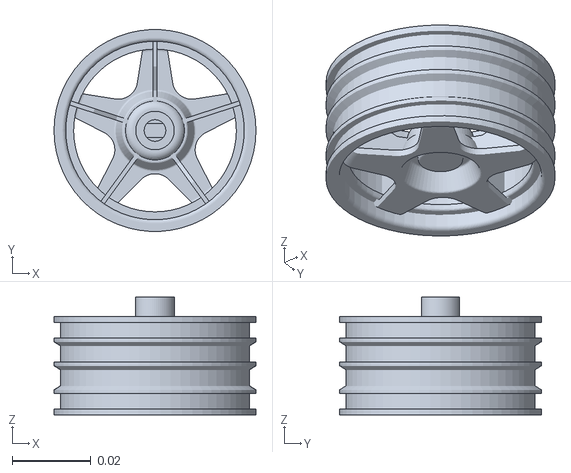
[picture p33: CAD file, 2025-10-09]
andino_description/meshes/andino/wheel_rim.stl
0.0514 x 0.0513 x 0.03

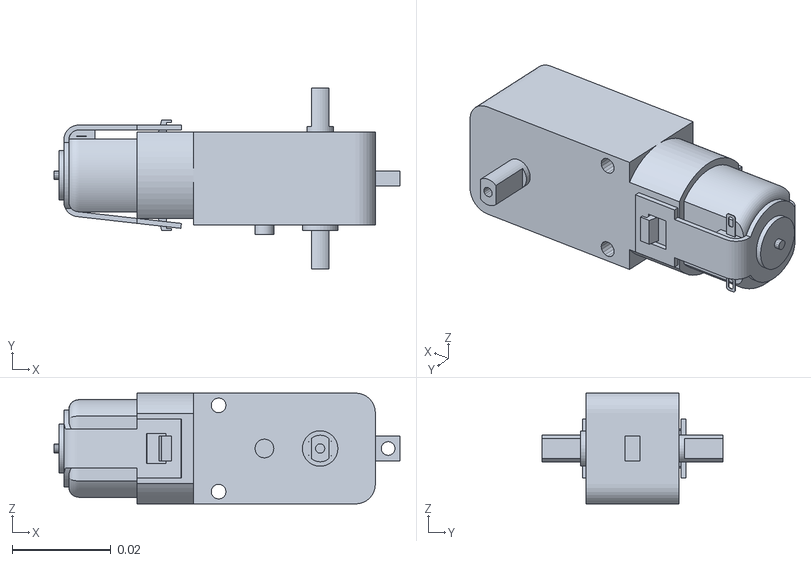
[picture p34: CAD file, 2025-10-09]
andino_description/meshes/andino/motor.stl
0.0702 x 0.0368 x 0.0225

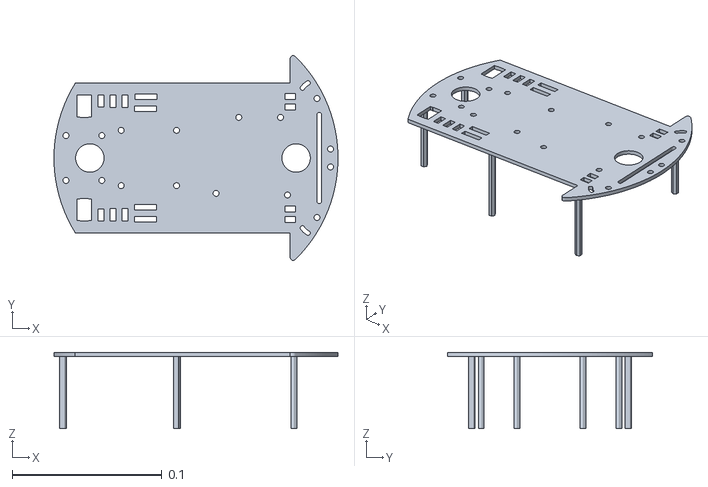
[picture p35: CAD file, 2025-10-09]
andino_description/meshes/andino/chassis_top.stl
0.19 x 0.137 x 0.051

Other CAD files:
andino_description/meshes/andino/chassis.stl
andino_description/meshes/andino/caster_wheel.stl

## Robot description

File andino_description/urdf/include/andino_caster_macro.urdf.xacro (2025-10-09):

<?xml version="1.0"?>
<robot xmlns:xacro="http://www.ros.org/wiki/xacro">
<!--
  Xacro macros were inspired on https://github.com/ros-mobile-robots/mobile_robot_description/wiki/
-->
<!-- ===================== Caster xacro =========================================

  Xacro to create caster links and the respective joints.

  params:
  - reflect [1/-1]: value to set the side of the caster;
  - use_fixed [bool]: wheter to use a fixed model or not
  - wheel_props [dictionary]: wheel properties;
  - base_props [dictionary]: base link properties;
  - mesh [string]: file name of the wheel mesh;
    - DEFAULT Value -> Empty string
-->

<!-- Caster wheel link & joint macro -->
  <xacro:macro name="caster_wheel" params="reflect use_fixed wheel_props locationright:=${0} scale:=''">
    <link name="caster_base_link">
      <xacro:box_inertia m="${wheel_props['base']['mass']}" x="${wheel_props['base']['size']['x']}" y="${wheel_props['base']['size']['y']}" z="${wheel_props['base']['size']['z']}" o_xyz="0.0 0.0 ${-wheel_props['base']['size']['z']/2.0}" o_rpy="0.0 0.0 0.0" />
      <xacro:if value="${wheel_props['base']['mesh'] != '' }" >
        <visual>
          <origin xyz="0 0 ${-wheel_props['base']['size']['z']/2.0}" rpy="0 0 0" />
          <geometry>
            <xacro:if value="${scale != '' }" >
              <mesh filename="package://andino_description/meshes/${robot_name}/${wheel_props['base']['mesh']}" scale="${scale}"/>
            </xacro:if>
            <xacro:if value="${scale == '' }" >
              <mesh filename="package://andino_description/meshes/${robot_name}/${wheel_props['base']['mesh']}" />
            </xacro:if>
          </geometry>
          <material name="silver"/>
        </visual>
      </xacro:if>
      <xacro:if value="${wheel_props['base']['mesh'] == '' }" >
        <visual>
          <origin xyz="0 0 ${-wheel_props['base']['size']['z']/2.0}" rpy="0 0 0" />
          <geometry>
            <box size="${wheel_props['base']['size']['x']} ${wheel_props['base']['size']['y']} ${wheel_props['base']['size']['z']}" />
          </geometry>
          <material name="red"/>
        </visual>
      </xacro:if>
      <collision>
        <origin xyz="0 0 ${-wheel_props['base']['size']['z']/2.0}" rpy="0 0 0" />
        <geometry>
          <box size="${wheel_props['base']['size']['x']} ${wheel_props['base']['size']['y']} ${wheel_props['base']['size']['z']}" />
        </geometry>
      </collision>
    </link>
    <joint name="caster_base_joint" type="fixed">
      <origin xyz="${wheel_props['base']['dx']} ${-wheel_props['base']['dy'] * locationright} ${wheel_props['base']['dz']}" rpy="0 0 0" />
      <parent link="base_link" />
      <child link="caster_base_link" />
      <axis xyz="0 0 1" />
      <dynamics damping="0.01" friction="0.0"/>
    </joint>


    <!-- caster hub -->
    <link name="caster_rotation_link">
      <xacro:box_inertia m="${wheel_props['hub']['mass']}" x="${wheel_props['hub']['size']['x']}" y="${wheel_props['hub']['size']['y']}" z="${wheel_props['hub']['size']['z']}" o_xyz="0.0 0.0 ${-wheel_props['hub']['size']['z']/2.0}" o_rpy="0.0 0.0 0.0" />
      <xacro:if value="${wheel_props['hub']['mesh'] != '' }" >
        <visual>
          <origin xyz="0 0 ${-wheel_props['hub']['size']['z']/2.0}" rpy="0 0 0" />
          <geometry>
            <xacro:if value="${scale != '' }" >
              <mesh filename="package://andino_description/meshes/${robot_name}/${wheel_props['hub']['mesh']}" scale="${scale}"/>
            </xacro:if>
            <xacro:if value="${scale == '' }" >
              <mesh filename="package://andino_description/meshes/${robot_name}/${wheel_props['hub']['mesh']}" />
            </xacro:if>
          </geometry>
          <material name="silver"/>
        </visual>
      </xacro:if>
      <xacro:if value="${wheel_props['hub']['mesh'] == '' }" >
        <visual>
          <origin xyz="0 0 ${-wheel_props['hub']['size']['z']/2.0}" rpy="0 0 0" />
          <geometry>
            <box size="${wheel_props['hub']['size']['x']} ${wheel_props['hub']['size']['y']} ${wheel_props['hub']['size']['z']}" />
          </geometry>
          <material name="red"/>
        </visual>
      </xacro:if>
      <collision>
        <origin xyz="0 0 ${-wheel_props['hub']['size']['z']/2.0}" rpy="0 0 0" />
        <geometry>
          <box size="${wheel_props['hub']['size']['x']} ${wheel_props['hub']['size']['y']} ${wheel_props['hub']['size']['z']}" />
        </geometry>
      </collision>
    </link>
    <xacro:if value="${use_fixed}">
      <joint name="caster_rotation_joint" type="fixed">
        <origin xyz="${wheel_props['hub']['dx']} ${-wheel_props['hub']['dy'] * locationright} ${wheel_props['hub']['dz']}" rpy="0 0 0" />
        <parent link="base_link" />
        <child link="caster_rotation_link" />
        <axis xyz="0 0 1" />
        <dynamics damping="0.01" friction="0.0"/>
      </joint>
    </xacro:if>
    <xacro:unless value="${use_fixed}">
      <joint name="caster_rotation_joint" type="continuous">
        <origin xyz="${wheel_props['hub']['dx']} ${-wheel_props['hub']['dy'] * locationright} ${wheel_props['hub']['dz']}" rpy="0 0 0" />
        <parent link="base_link" />
        <child link="caster_rotation_link" />
        <axis xyz="0 0 1" />
        <dynamics damping="0.01" friction="0.0"/>
      </joint>
    </xacro:unless>


    <!-- caster wheel -->
    <link name="caster_wheel_link">
      <xacro:cylinder_inertia m="${wheel_props['wheel']['mass']}" r="${wheel_props['wheel']['radius']}" l="${wheel_props['wheel']['length']}">
      </xacro:cylinder_inertia>
      <xacro:if value="${wheel_props['wheel']['mesh'] != '' }" >
        <visual>
          <origin xyz="0 0 0" rpy="0 0 0" />
          <geometry>
            <xacro:if value="${scale != '' }" >
              <mesh filename="package://andino_description/meshes/${robot_name}/${wheel_props['wheel']['mesh']}" scale="${scale}"/>
            </xacro:if>
            <xacro:if value="${scale == '' }" >
              <mesh filename="package://andino_description/meshes/${robot_name}/${wheel_props['wheel']['mesh']}" />
            </xacro:if>
          </geometry>
          <material name="black"/>
        </visual>
      </xacro:if>
      <xacro:if value="${wheel_props['wheel']['mesh'] == '' }" >
        <visual>
          <origin xyz="0 0 0" rpy="${pi/2} 0 0" />
          <geometry>
            <cylinder length="${wheel_props['wheel']['length']}" radius="${wheel_props['wheel']['radius']}" />
          </geometry>
          <material name="red"/>
        </visual>
      </xacro:if>
      <collision>
        <origin xyz="0 0 0" rpy="${pi/2} 0 0" />
        <geometry>
          <cylinder length="${wheel_props['wheel']['length']}" radius="${wheel_props['wheel']['radius']}" />
        </geometry>
      </collision>
    </link>
    <xacro:if value="${use_fixed}">
      <joint name="caster_wheel_joint" type="fixed">
        <origin xyz="${wheel_props['wheel']['dx']} ${-wheel_props['wheel']['dy'] * locationright} ${wheel_props['wheel']['dz']}" rpy="0 0 0" />
        <parent link="caster_rotation_link" />
        <child link="caster_wheel_link" />
        <axis xyz="0 1 0" />
      </joint>
    </xacro:if>
    <xacro:unless value="${use_fixed}">
      <joint name="caster_wheel_joint" type="continuous">
        <origin xyz="${wheel_props['wheel']['dx']} ${-wheel_props['wheel']['dy'] * locationright} ${wheel_props['wheel']['dz']}" rpy="0 0 0" />
        <parent link="caster_rotation_link" />
        <child link="caster_wheel_link" />
        <axis xyz="0 1 0" />
      </joint>
    </xacro:unless>
  </xacro:macro>

</robot>

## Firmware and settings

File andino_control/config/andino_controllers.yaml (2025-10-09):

controller_manager:
  ros__parameters:
    update_rate: 50  # Hz

    diff_controller:
      type: diff_drive_controller/DiffDriveController

    joint_state_broadcaster:
      type: joint_state_broadcaster/JointStateBroadcaster

diff_controller:
  ros__parameters:
    # See https://github.com/ros-controls/ros2_controllers/blob/humble/diff_drive_controller/src/diff_drive_controller_parameter.yaml
    publish_rate: 50.0
    left_wheel_names: ['left_wheel_joint']
    right_wheel_names: ['right_wheel_joint']
    wheels_per_side: 1
    wheel_separation: 0.137
    wheel_radius: 0.035
    odom_frame_id: odom
    base_frame_id: base_link
    enable_odom_tf: true
    use_stamped_vel: false

    linear.x.has_velocity_limits: false
    linear.x.has_acceleration_limits: false
    linear.x.has_jerk_limits: false
    linear.x.max_velocity: 0.0
    linear.x.min_velocity: 0.0
    linear.x.max_acceleration: 0.0
    linear.x.min_acceleration: 0.0
    linear.x.max_jerk: 0.0
    linear.x.min_jerk: 0.0

    angular.z.has_velocity_limits: false
    angular.z.has_acceleration_limits: false
    angular.z.has_jerk_limits: false
    angular.z.max_velocity: 0.0
    angular.z.min_velocity: 0.0
    angular.z.max_acceleration: 0.0
    angular.z.min_acceleration: 0.0
    angular.z.max_jerk: 0.0
    angular.z.min_jerk: 0.0

# Commented out as no parameters are passed to this controller:
#
# joint_state_broadcaster:
#   ros__parameters:

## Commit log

2025-10-09 Primer commit
    [RobotChassis.STL, andino.urdf.xacro, andino_caster_macro.urdf.xacro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]
2025-11-18 Agregar navigation2 como carpeta normal
    [cardboard_box.sdf]
